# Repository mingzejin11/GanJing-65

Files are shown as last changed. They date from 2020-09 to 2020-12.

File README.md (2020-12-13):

# GanJing 65
**A 65% keyboard with a rotary encoder, OLED screen and USB-c. Made using only through-hole components for easy soldering.**

[Bill of materials](https://octopart.com/bom-tool/HPiXAxIx)

## Layout options
The GanJing 65 supports ISO layouts, as well as stepped caps lock keys. The bottom row also supports alternate layouts.

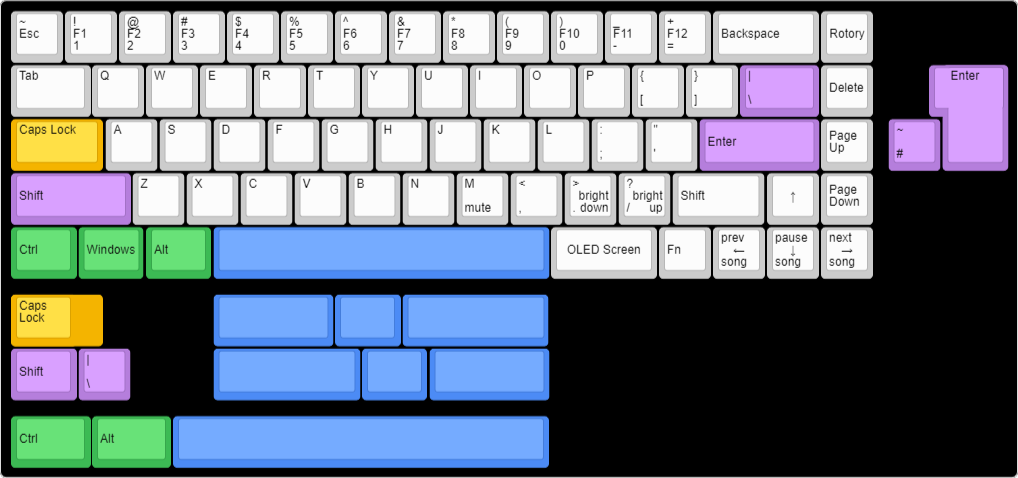
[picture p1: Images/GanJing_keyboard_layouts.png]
GanJing-keyboard

## Schematic
Inspired by the [Discipline](https://github.com/coseyfannitutti/discipline) and [Pheromone](https://github.com/luantty2/pheromone_keyboard) keyboards.

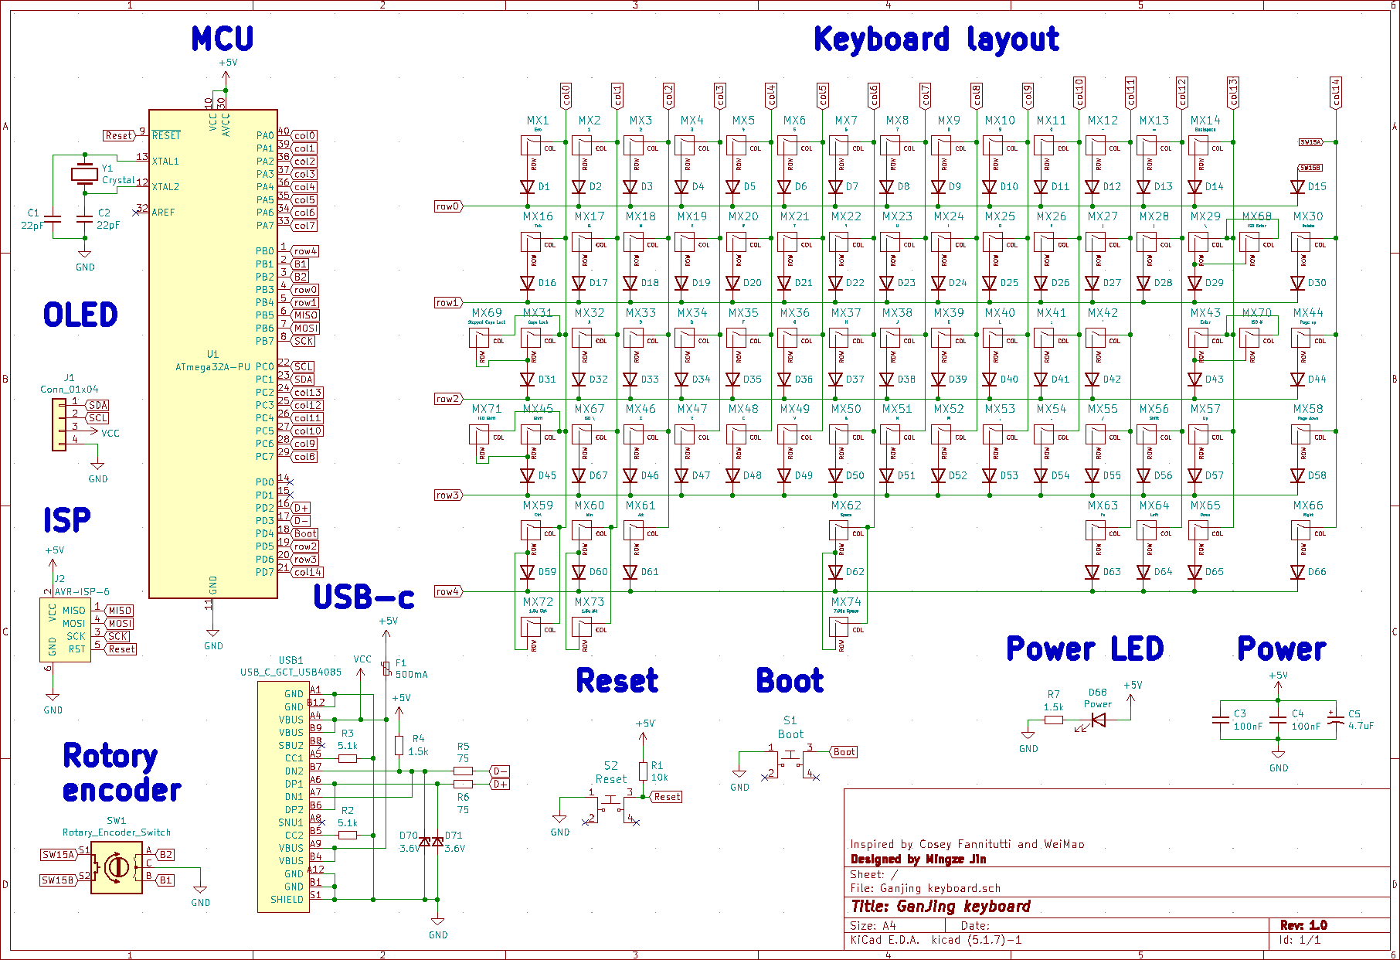
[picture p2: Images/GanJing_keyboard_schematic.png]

## PCB layout
### Front
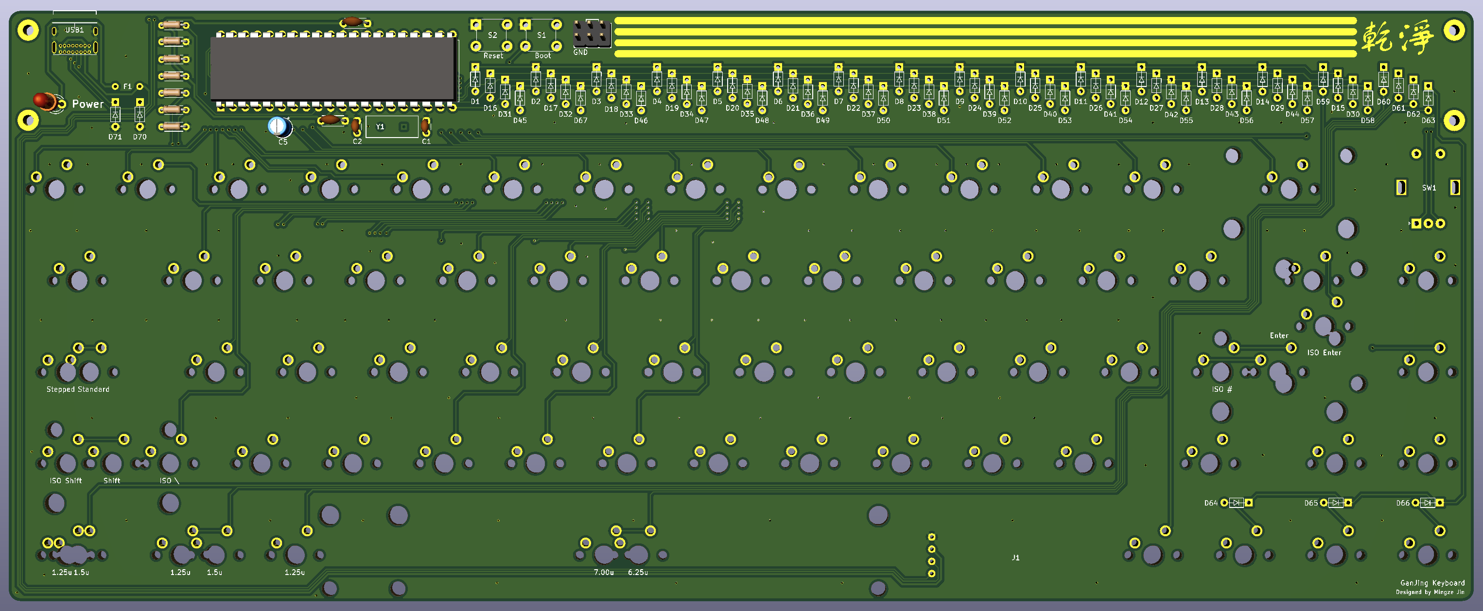
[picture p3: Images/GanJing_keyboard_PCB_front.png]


### Back
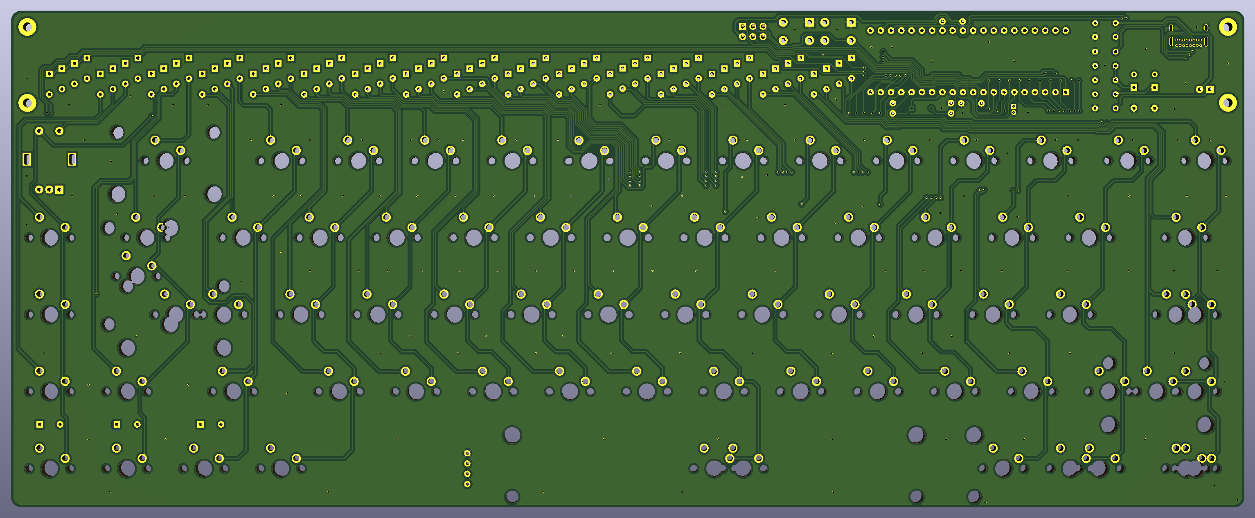
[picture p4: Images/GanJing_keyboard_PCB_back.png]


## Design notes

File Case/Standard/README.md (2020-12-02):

# Lasercut Acrylic Case

GanJing keyboard acrylic case inspired by the discipline case. The entire case is made of clear acrylic, but if you want to print your own, feel free to use different colours or even materials (recommended alternative to acrylic is POM for the plate piece).

## Part Dimensions/Thickness (Top to Bottom)
1. GanJing-top-1.dxf - 320.9 x 138.8 mm - ***3mm***
2. GanJing-top-2.dxf - 320.9 x 138.8 mm - ***4.5mm***
3. GanJing-plate.dxf - 320.9 x 138.8 mm - ***1.5mm***
4. GanJing-open-layer.dxf - 320.9 x 138.8 mm - ***4.5mm***
5. GanJing-closed-layer.dxf - 320.9 x 138.8 mm - ***3mm***
6. GanJing-bottom.dxf - 320.9 x 138.8 - ***3mm***
7. GanJing-foot-1.dxf - 276.5 x 28mm - ***4.5mm***
8. GanJing-foot-2.dxf - 272.5 x 24mm - ***4.5mm***

## Screws and Standoffs
1. 3 x m2x4 standoffs
2. 12 x m2x13 standoffs
3. 3 x m2x4mm screws
4. 24 x m2x5mm screws
5. 3 x m2x6mm screws

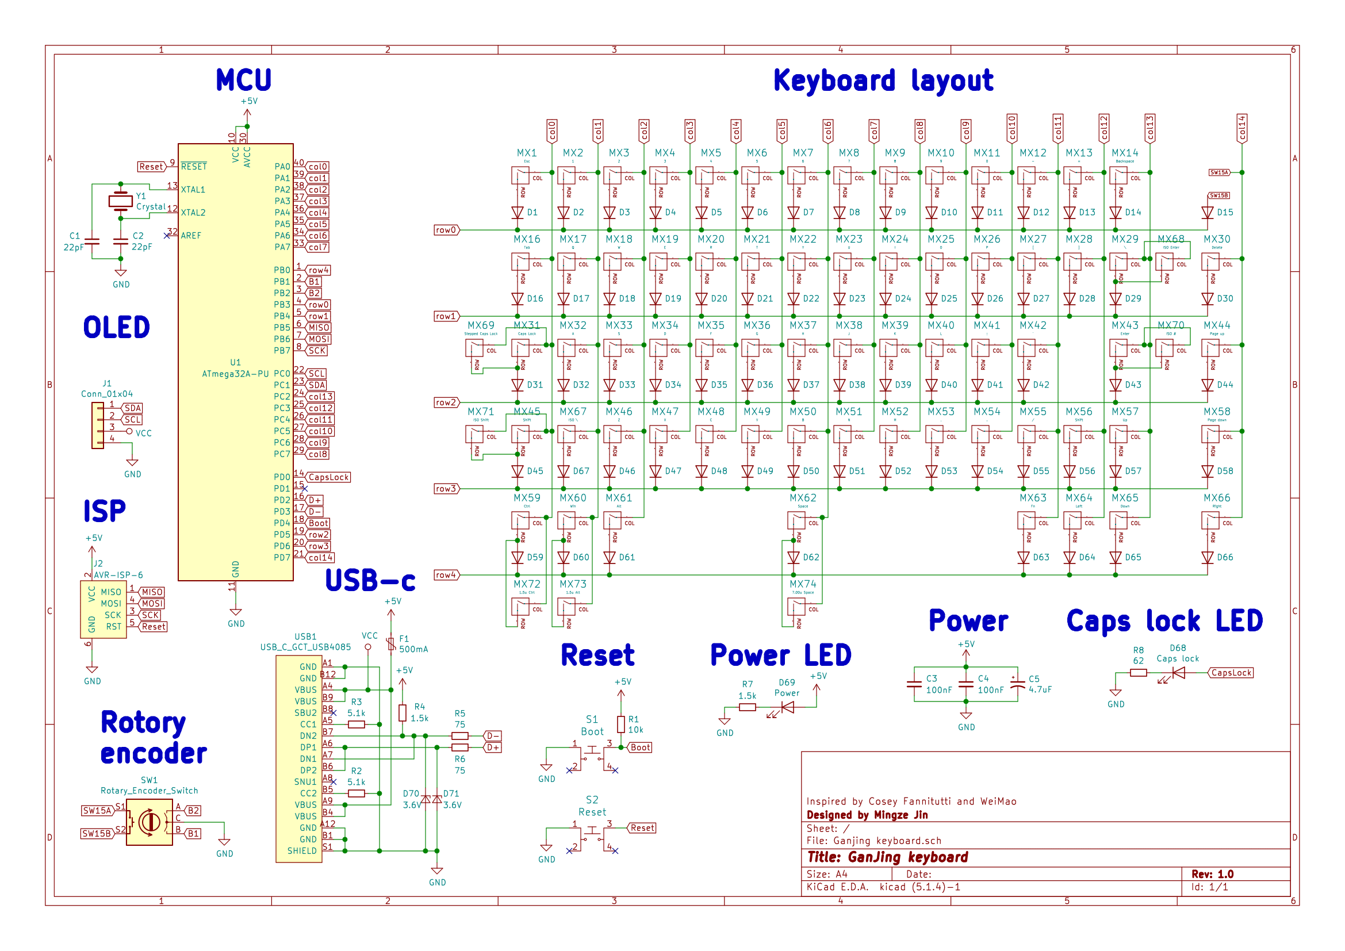
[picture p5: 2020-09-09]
Images/GanJing_keyboard_schematic 1.png

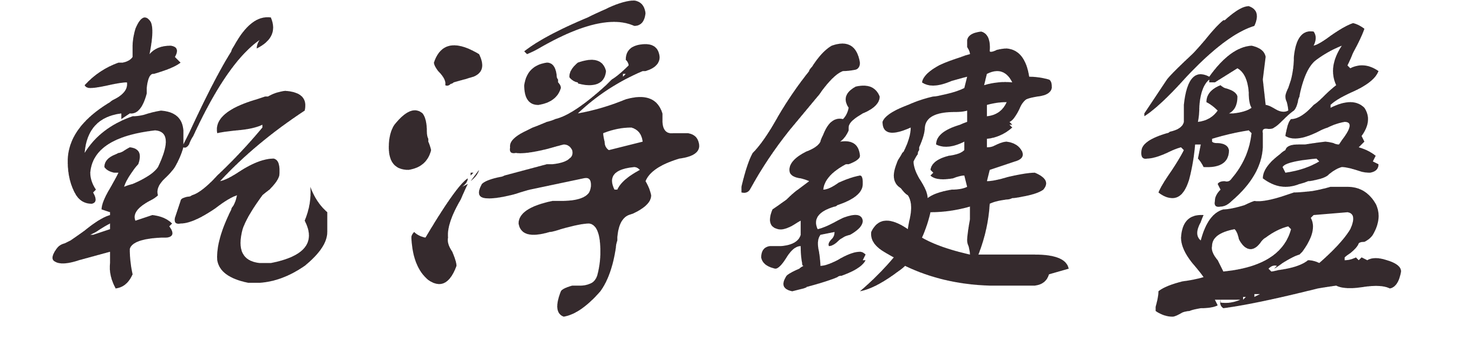
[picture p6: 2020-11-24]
Images/GanJing keyboard characters.png

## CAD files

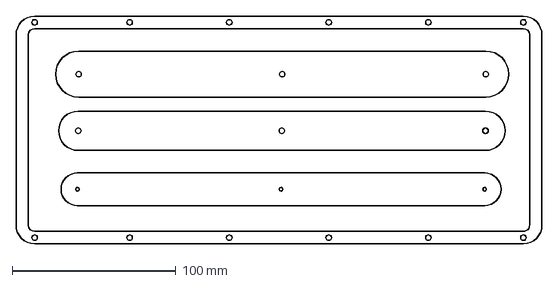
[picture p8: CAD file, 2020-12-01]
Case/Standard/GanJing-closed-layer-plus-feet.dxf
320.9 x 138.8 mm

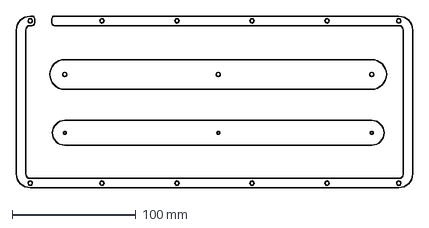
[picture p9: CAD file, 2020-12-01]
Case/Standard/GanJing-open-layer-plus-feet.dxf
320.9 x 138.8 mm

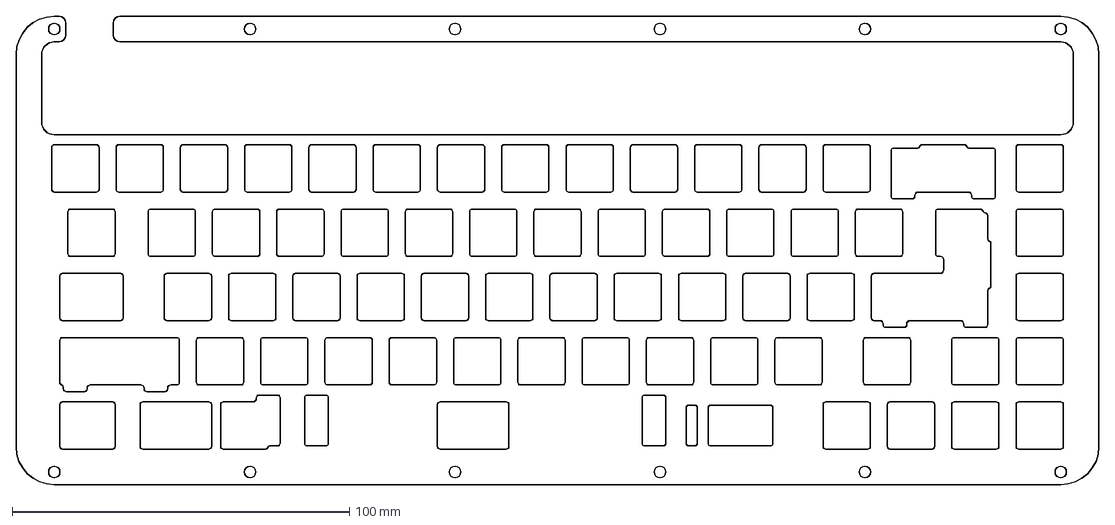
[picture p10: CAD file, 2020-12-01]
Case/Standard/GanJing-plate.dxf
320.9 x 138.8 mm

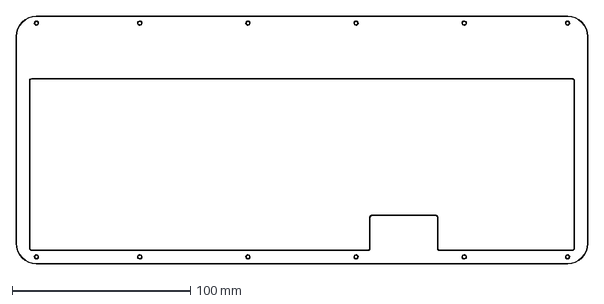
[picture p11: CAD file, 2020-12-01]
Case/Standard/GanJing-top-1.dxf
320.9 x 138.8 mm

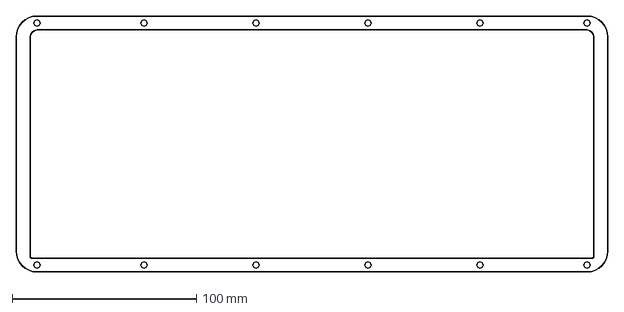
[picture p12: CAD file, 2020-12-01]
Case/Standard/GanJing-top-2.dxf
320.9 x 138.8 mm

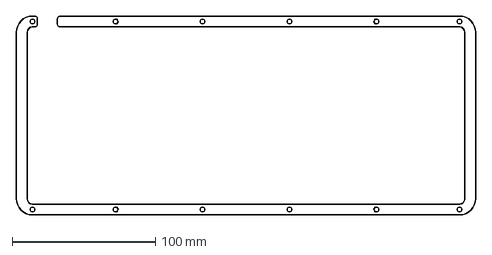
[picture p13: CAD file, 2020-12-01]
Case/Standard/GanJing-open-layer.dxf
320.9 x 138.8 mm

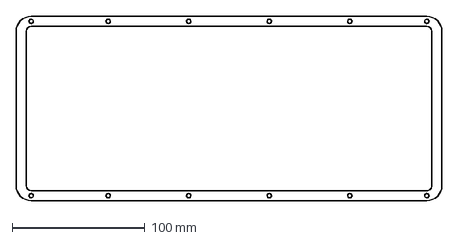
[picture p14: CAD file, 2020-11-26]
Case/Standard/GanJing-closed-layer.dxf
320.9 x 138.8 mm

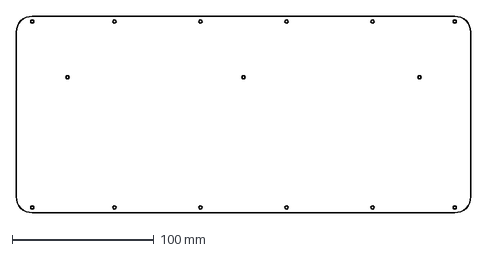
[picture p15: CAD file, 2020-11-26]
Case/Standard/GanJing-bottom.dxf
320.9 x 138.8 mm

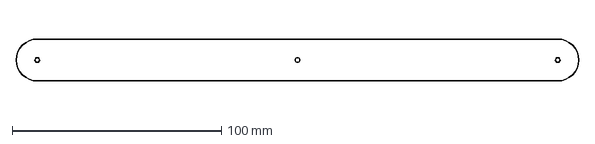
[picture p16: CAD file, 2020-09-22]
Case/Standard/GanJing-foot-2.dxf
268.5 x 20.0 mm

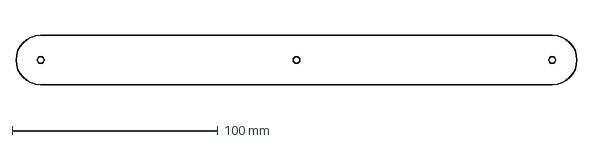
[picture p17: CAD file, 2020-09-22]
Case/Standard/GanJing-foot-1.dxf
272.5 x 24.0 mm

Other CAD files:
Case/Standard/GanJing.Drawing.JD.dwg

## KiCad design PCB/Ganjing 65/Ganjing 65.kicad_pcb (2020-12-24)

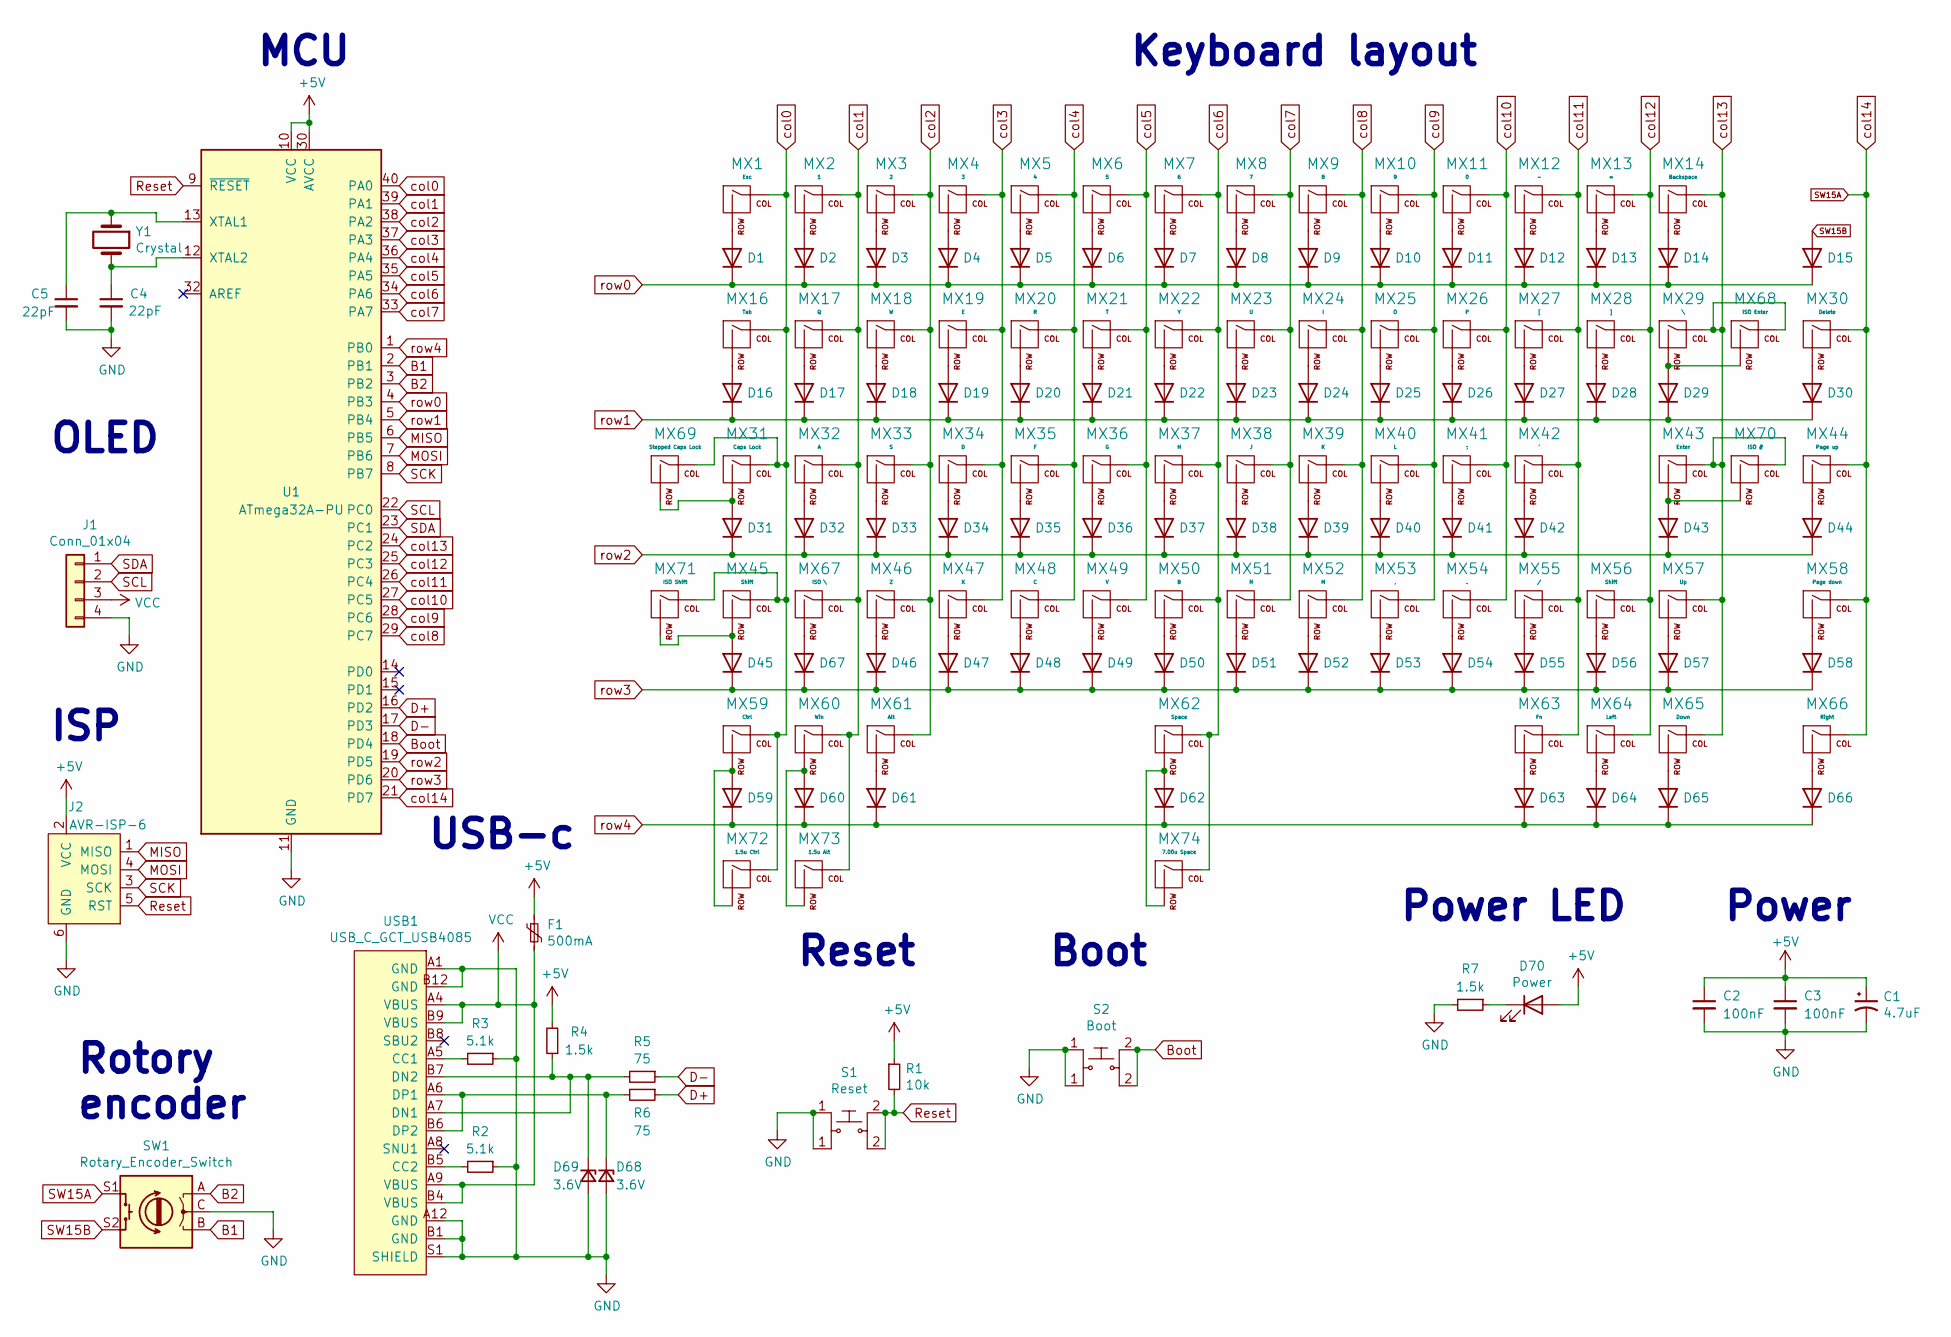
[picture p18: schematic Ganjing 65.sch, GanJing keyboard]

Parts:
C1: 4.7uF; CP_Radial_D4.0mm_P1.50mm; Mouser # 647-UMT1H4R7MDD1TP
C2, C3: 100nF; C_Disc_D4.3mm_W1.9mm_P5.00mm
C4, C5: 22pF; C_Disc_D3.0mm_W1.6mm_P2.50mm; Digikey # 490-11879-ND
D1, D2, D3, D4, D5, D6, D7, D8, D9, D10, D11, D12, D13, D14, D15, D16, D17, D18, D19, D20, D21, D22, D23, D24, D25, D26, D27, D28, D29, D30, D31, D32, D33, D34, D35, D36, D37, D38, D39, D40, D41, D42, D43, D44, D45, D46, D47, D48, D49, D50, D51, D52, D53, D54, D55, D56, D57, D58, D59, D60, D61, D62, D63, D64, D65, D66, D67: D; D_DO-35_SOD27_P5.08mm_Horizontal; Digikey # 1N4148FSTR-ND
D68, D69: 3.6V; D_DO-35_SOD27_P5.08mm_Horizontal; Mouser # 78-TZX3V6A
D70: Power; LED_D3.0mm; Digikey # 160-1140-ND
F1: 500mA; polyfuse_5.1mm; Digikey # MF-R050-ND
J1: Conn_01x04; ssd1306_128x32_oled
J2: AVR-ISP-6; AVR_ICSP_3x2; Digikey # 609-4934-ND
MX1: Esc; MXOnly-1U-NoLED
MX2: 1; MXOnly-1U-NoLED
MX3: 2; MXOnly-1U-NoLED
MX4: 3; MXOnly-1U-NoLED
MX5: 4; MXOnly-1U-NoLED
MX6: 5; MXOnly-1U-NoLED
MX7: 6; MXOnly-1U-NoLED
MX8: 7; MXOnly-1U-NoLED
MX9: 8; MXOnly-1U-NoLED
MX10: 9; MXOnly-1U-NoLED
MX11: 0; MXOnly-1U-NoLED
MX12: -; MXOnly-1U-NoLED
MX13: =; MXOnly-1U-NoLED
MX14: Backspace; MXOnly-2U-NoLED
MX16: Tab; MXOnly-1.5U-NoLED
MX17: Q; MXOnly-1U-NoLED
MX18: W; MXOnly-1U-NoLED
MX19: E; MXOnly-1U-NoLED
MX20: R; MXOnly-1U-NoLED
MX21: T; MXOnly-1U-NoLED
MX22: Y; MXOnly-1U-NoLED
MX23: U; MXOnly-1U-NoLED
MX24: I; MXOnly-1U-NoLED
MX25: O; MXOnly-1U-NoLED
MX26: P; MXOnly-1U-NoLED
MX27: [; MXOnly-1U-NoLED
MX28: ]; MXOnly-1U-NoLED
MX29: \\; MXOnly-1.5U-NoLED
MX30: Delete; MXOnly-1U-NoLED
MX31: Caps Lock; MXOnly-1.75U-NoLED
MX32: A; MXOnly-1U-NoLED
MX33: S; MXOnly-1U-NoLED
MX34: D; MXOnly-1U-NoLED
MX35: F; MXOnly-1U-NoLED
MX36: G; MXOnly-1U-NoLED
MX37: H; MXOnly-1U-NoLED
MX38: J; MXOnly-1U-NoLED
MX39: K; MXOnly-1U-NoLED
MX40: L; MXOnly-1U-NoLED
MX41: ;; MXOnly-1U-NoLED
MX42: '; MXOnly-1U-NoLED
MX43: Enter; MXOnly-2.25U-NoLED
MX44: Page up; MXOnly-1U-NoLED
MX45: Shift; MXOnly-2.25U-NoLED
MX46: Z; MXOnly-1U-NoLED
MX47: X; MXOnly-1U-NoLED
MX48: C; MXOnly-1U-NoLED
MX49: V; MXOnly-1U-NoLED
MX50: B; MXOnly-1U-NoLED
MX51: N; MXOnly-1U-NoLED
MX52: M; MXOnly-1U-NoLED
MX53: ,; MXOnly-1U-NoLED
MX54: .; MXOnly-1U-NoLED
MX55: /; MXOnly-1U-NoLED
MX56: Shift; MXOnly-1.75U-NoLED
MX57: Up; MXOnly-1U-NoLED
MX58: Page down; MXOnly-1U-NoLED
MX59: Ctrl; MXOnly-1.25U-NoLED
MX60: Win; MXOnly-1.25U-NoLED
MX61: Alt; MXOnly-1.25U-NoLED
MX62: Space; MXOnly-6.25U-ReversedStabilizers-NoLED
MX63: Fn; MXOnly-1U-NoLED
MX64: Left; MXOnly-1U-NoLED
MX65: Down; MXOnly-1U-NoLED
MX66: Right; MXOnly-1U-NoLED
MX67: ISO \\; MXOnly-1U-NoLED
MX68: ISO Enter; MXOnly-ISO-ReversedStabilizers-NoLED
MX69: Stepped Caps Lock; MXOnly-1.75U-Stepped-NoLED
MX70: ISO #; MXOnly-1U-NoLED
MX71: ISO Shift; MXOnly-1.25U-NoLED
MX72: 1.5u Ctrl; MXOnly-1.5U-NoLED
MX73: 1.5u Alt; MXOnly-1.5U-NoLED
MX74: 7.00u Space; MXOnly-7U-ReversedStabilizers-NoLED
R1: 10k; R_Axial_DIN0204_L3.6mm_D1.6mm_P5.08mm_Horizontal
R2, R3: 5.1k; R_Axial_DIN0204_L3.6mm_D1.6mm_P5.08mm_Horizontal; Mouser # 603-MFR-12FTF52-5K1
R4, R7: 1.5k; R_Axial_DIN0204_L3.6mm_D1.6mm_P5.08mm_Horizontal; Mouser # 603-MFR-12FTF52-1K5
R5, R6: 75; R_Axial_DIN0204_L3.6mm_D1.6mm_P5.08mm_Horizontal; Mouser # 603-CFR-12JR-52-75R
S1: Reset; SW_PUSH_6mm
S2: Boot; SW_PUSH_6mm
SW1: Rotary_Encoder_Switch; RotaryEncoder_Alps_EC11E-Switch_Vertical_H20mm; Mouser # 688-EC11E183440C
U1: ATmega32A-PU; DIP-40_W15.24mm; Digikey # ATMEGA32A-PU-ND
USB1: USB_C_GCT_USB4085; Digikey # 2073-USB4085-GF-ATR-ND
Y1: Crystal; Crystal_HC49-4H_Vertical; Mouser # 815-ABL16000MHZB4YT

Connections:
+5V: C1.1, C2.1, C3.1, D70.2 (A), F1.1, J2.2 (VCC), R1.1, R4.2, U1.10 (VCC), U1.30 (AVCC)
B1: SW1.B, U1.2 (PB1)
B2: SW1.A, U1.3 (PB2)
Boot: S2.2, U1.18 (PD4)
D+: R6.1, U1.16 (PD2)
D-: R5.1, U1.17 (PD3)
GND: C1.2, C2.2, C3.2, C4.2, C5.2, D68.2 (A), D69.2 (A), J1.4, J2.6 (GND), R2.1, R3.1, R7.2, S1.1, S2.1, SW1.C, U1.11 (GND), U1.31 (GND), USB1.A1 (GND), USB1.A12 (GND), USB1.B1 (GND), USB1.B12 (GND), USB1.S1 (SHIELD)
MISO: J2.1 (MISO), U1.6 (PB5)
MOSI: J2.4 (MOSI), U1.7 (PB6)
unnamed: C4.1, U1.12 (XTAL2), Y1.2
unnamed: C5.1, U1.13 (XTAL1), Y1.1
unnamed: D1.2, MX1.2 (ROW)
unnamed: D2.2, MX2.2 (ROW)
unnamed: D3.2, MX3.2 (ROW)
unnamed: D4.2, MX4.2 (ROW)
unnamed: D5.2, MX5.2 (ROW)
unnamed: D6.2, MX6.2 (ROW)
unnamed: D7.2, MX7.2 (ROW)
unnamed: D8.2, MX8.2 (ROW)
unnamed: D9.2, MX9.2 (ROW)
unnamed: D10.2, MX10.2 (ROW)
unnamed: D11.2, MX11.2 (ROW)
unnamed: D12.2, MX12.2 (ROW)
unnamed: D13.2, MX13.2 (ROW)
unnamed: D14.2, MX14.2 (ROW)
unnamed: D16.2, MX16.2 (ROW)
unnamed: D17.2, MX17.2 (ROW)
unnamed: D18.2, MX18.2 (ROW)
unnamed: D19.2, MX19.2 (ROW)
unnamed: D20.2, MX20.2 (ROW)
unnamed: D21.2, MX21.2 (ROW)
unnamed: D22.2, MX22.2 (ROW)
unnamed: D23.2, MX23.2 (ROW)
unnamed: D24.2, MX24.2 (ROW)
unnamed: D25.2, MX25.2 (ROW)
unnamed: D26.2, MX26.2 (ROW)
unnamed: D27.2, MX27.2 (ROW)
unnamed: D28.2, MX28.2 (ROW)
unnamed: D29.2, MX29.2 (ROW), MX68.2 (ROW)
unnamed: D30.2, MX30.2 (ROW)
unnamed: D31.2, MX31.2 (ROW), MX69.2 (ROW)
unnamed: D32.2, MX32.2 (ROW)
unnamed: D33.2, MX33.2 (ROW)
unnamed: D34.2, MX34.2 (ROW)
unnamed: D35.2, MX35.2 (ROW)
unnamed: D36.2, MX36.2 (ROW)
unnamed: D37.2, MX37.2 (ROW)
unnamed: D38.2, MX38.2 (ROW)
unnamed: D39.2, MX39.2 (ROW)
unnamed: D40.2, MX40.2 (ROW)
unnamed: D41.2, MX41.2 (ROW)
unnamed: D42.2, MX42.2 (ROW)
unnamed: D43.2, MX43.2 (ROW), MX70.2 (ROW)
unnamed: D44.2, MX44.2 (ROW)
unnamed: D45.2, MX45.2 (ROW), MX71.2 (ROW)
unnamed: D46.2, MX46.2 (ROW)
unnamed: D47.2, MX47.2 (ROW)
unnamed: D48.2, MX48.2 (ROW)
unnamed: D49.2, MX49.2 (ROW)
unnamed: D50.2, MX50.2 (ROW)
unnamed: D51.2, MX51.2 (ROW)
unnamed: D52.2, MX52.2 (ROW)
unnamed: D53.2, MX53.2 (ROW)
unnamed: D54.2, MX54.2 (ROW)
unnamed: D55.2, MX55.2 (ROW)
unnamed: D56.2, MX56.2 (ROW)
unnamed: D57.2, MX57.2 (ROW)
unnamed: D58.2, MX58.2 (ROW)
unnamed: D59.2, MX59.2 (ROW), MX72.2 (ROW)
unnamed: D60.2, MX60.2 (ROW), MX73.2 (ROW)
unnamed: D61.2, MX61.2 (ROW)
unnamed: D62.2, MX62.2 (ROW), MX74.2 (ROW)
unnamed: D63.2, MX63.2 (ROW)
unnamed: D64.2, MX64.2 (ROW)
unnamed: D65.2, MX65.2 (ROW)
unnamed: D66.2, MX66.2 (ROW)
unnamed: D67.2, MX67.2 (ROW)
unnamed: D68.1 (K), R6.2, USB1.A6 (DP1), USB1.B6 (DP2)
unnamed: D69.1 (K), R4.1, R5.2, USB1.A7 (DN1), USB1.B7 (DN2)
unnamed: D70.1 (K), R7.1
unnamed: R2.2, USB1.B5 (CC2)
unnamed: R3.2, USB1.A5 (CC1)
Reset: J2.5 (RST), R1.2, S1.2, U1.9 (~RESET)
SCK: J2.3 (SCK), U1.8 (PB7)
SCL: J1.2, U1.22 (PC0)
SDA: J1.1, U1.23 (PC1)
SW15A: MX30.1 (COL), MX44.1 (COL), MX58.1 (COL), MX66.1 (COL), SW1.S1, U1.21 (PD7)
SW15B: D15.2, SW1.S2
VCC: F1.2, J1.3, USB1.A4 (VBUS), USB1.A9 (VBUS), USB1.B4 (VBUS), USB1.B9 (VBUS)
col0: MX1.1 (COL), MX16.1 (COL), MX31.1 (COL), MX45.1 (COL), MX59.1 (COL), MX69.1 (COL), MX71.1 (COL), MX72.1 (COL), U1.40 (PA0)
col1: MX2.1 (COL), MX17.1 (COL), MX32.1 (COL), MX60.1 (COL), MX67.1 (COL), MX73.1 (COL), U1.39 (PA1)
col2: MX3.1 (COL), MX18.1 (COL), MX33.1 (COL), MX46.1 (COL), MX61.1 (COL), U1.38 (PA2)
col3: MX4.1 (COL), MX19.1 (COL), MX34.1 (COL), MX47.1 (COL), U1.37 (PA3)
col4: MX5.1 (COL), MX20.1 (COL), MX35.1 (COL), MX48.1 (COL), U1.36 (PA4)
col5: MX6.1 (COL), MX21.1 (COL), MX36.1 (COL), MX49.1 (COL), U1.35 (PA5)
col6: MX7.1 (COL), MX22.1 (COL), MX37.1 (COL), MX50.1 (COL), MX62.1 (COL), MX74.1 (COL), U1.34 (PA6)
col7: MX8.1 (COL), MX23.1 (COL), MX38.1 (COL), MX51.1 (COL), U1.33 (PA7)
col8: MX9.1 (COL), MX24.1 (COL), MX39.1 (COL), MX52.1 (COL), U1.29 (PC7)
col9: MX10.1 (COL), MX25.1 (COL), MX40.1 (COL), MX53.1 (COL), U1.28 (PC6)
col10: MX11.1 (COL), MX26.1 (COL), MX41.1 (COL), MX54.1 (COL), U1.27 (PC5)
col11: MX12.1 (COL), MX27.1 (COL), MX42.1 (COL), MX55.1 (COL), MX63.1 (COL), U1.26 (PC4)
col12: MX13.1 (COL), MX28.1 (COL), MX56.1 (COL), MX64.1 (COL), U1.25 (PC3)
col13: MX14.1 (COL), MX29.1 (COL), MX43.1 (COL), MX57.1 (COL), MX65.1 (COL), MX68.1 (COL), MX70.1 (COL), U1.24 (PC2)
row0: D1.1, D2.1, D3.1, D4.1, D5.1, D6.1, D7.1, D8.1, D9.1, D10.1, D11.1, D12.1, D13.1, D14.1, D15.1, U1.4 (PB3)
row1: D16.1, D17.1, D18.1, D19.1, D20.1, D21.1, D22.1, D23.1, D24.1, D25.1, D26.1, D27.1, D28.1, D29.1, D30.1, U1.5 (PB4)
row2: D31.1, D32.1, D33.1, D34.1, D35.1, D36.1, D37.1, D38.1, D39.1, D40.1, D41.1, D42.1, D43.1, D44.1, U1.19 (PD5)
row3: D45.1, D46.1, D47.1, D48.1, D49.1, D50.1, D51.1, D52.1, D53.1, D54.1, D55.1, D56.1, D57.1, D58.1, D67.1, U1.20 (PD6)
row4: D59.1, D60.1, D61.1, D62.1, D63.1, D64.1, D65.1, D66.1, U1.1 (PB0)

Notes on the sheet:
Rotory encoder
Keyboard layout
OLED
ISP
MCU
Power
Reset
Power LED
USB-c
Boot

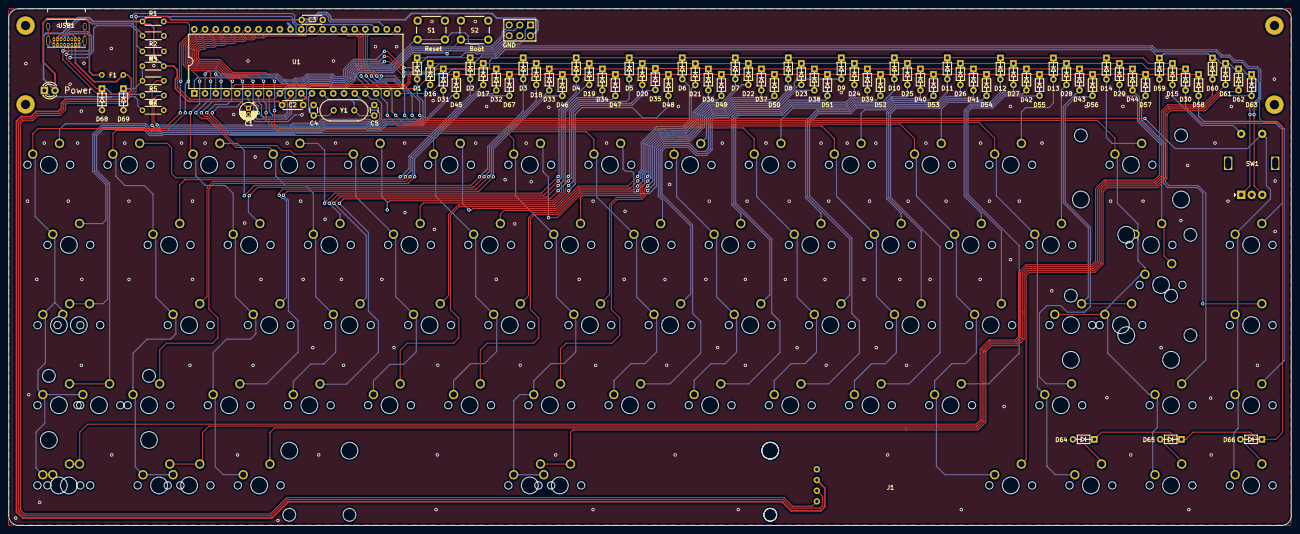
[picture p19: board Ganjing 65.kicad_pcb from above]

Board: 2 copper layers, 304.8 x 122.8 mm, 169 parts (0 on the bottom side), 108 nets.

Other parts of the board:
L1: LOGO; GanJing logo
REF1, REF2, REF6: MountingHole_2.2mm_M2_Pad
REFl: MountingHole_2.2mm_M2_Pad

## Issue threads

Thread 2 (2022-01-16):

Troubleshooting

dayofdoom, 2022-01-16:
Hello,

I've been trying to get my GanJing65 to work. I've checked all the component placements and solder joints, they appear to be without issue. The power LED lights up when plugged in. I can't get the board to be visable however - see the output from QMK toolbox.
```
    avrdude: warning: cannot set sck period. please check for usbasp firmware update.
    avrdude: error: program enable: target doesn't answer. 1
    avrdude: initialization failed, rc=-1
             Double check connections and try again, or use -F to override
             this check.

    avrdude done.  Thank you.
```

Part of my troubleshooting has been using my [LCK75](https://github.com/lyso1/LCK75) to flash the MCU since I wasn't able to with the GanJing65. I was able to successfully burn the bootloader and flash the GanJing firmware, so I know the chip is good. The computer recognized the board after flashing too.

After flashing the chip, I put it back into the GanJing but it still won't show up. It feels like there is a short somewhere or something but I've hit my skill wall and I'm not sure where to go from here. Do you have any suggestions?

mingzejin11, 2022-01-16:
First of all, lemme just start by saying I really appreciate your interest in my project! You're the first person I'm aware of who's trying to actually build it besides myself.

Onto your question, I'll be completely transparent, I ran into the same wall that you're running into right now with programming. That's why I don't have a prototype on video, I wasn't able to flash my microcontroller for the same reasons. I'm currently working on a second revision of the GanJing 65 (although I might rename it to the GanJing 70 because of the different layout), you can find it on my GitHub and it uses far fewer components and relies on the Elite-c for the MCU. I'm currently working on it right now and have a working prototype, but I'm still in 3rd-year electrical engineering so I haven't found the time to prototype the case quite yet, after this week's assignments and labs are done, I'll be laser cutting the case.

The GanJing 70 is designed to actually be gasket mounted and has a larger OLED with a Pikachu animation on it that I made(I figured the Bongo Cat one was a little overused).

Okay, I'm realizing now that I actually didn't help you at ALL with this response haha. Try checking out the bootloader stuff for the Discipline board, these two boards should use the same bootloader. That's the only real suggestion I have. I'm so sorry I can't be more help, but I promise the GanJing 70 is much easier to assemble and work with if you're up for that challenge :)

dayofdoom, 2022-01-24:
I'm going to try the make the ganjing v2, thats for sure. Looks very cool. I'm commited to getting this v1 to work too. I got the bootloader on the MCU using a different PCB (non GanJing), so I know the bootloader works ok. What I've noticed is that no matter what, when the MCU is in the GanJing, it can't be seen by the computer. The reset and boot buttons don't work either. In theroy, boot should reboot the board but the LED doesn't cycle when I press boot. My gut tells me something needs to jumpered from A to B to fix a missing connection but I'm a hobbyist, not a EE. Any thoughts?

dayofdoom, 2022-01-26:
I think the OLED pinout is reversed? See the sample image below? I think this explains why the LED was getting power but the OLED wasn't. Could this impact anything else?
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

dayofdoom, 2022-03-06:
Following up on this - I'm still not able to get the board to flash successfully BUT I've been able to flash the MCU in a different board and then get the GanJing65 to work. So, progress :) I'm going to close this because you've already moved on to v2.

Closed 2022-03-06.

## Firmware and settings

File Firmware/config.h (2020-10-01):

/* Copyright 2019 mingzejin11
 *
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
 * You should have received a copy of the GNU General Public License
 * along with this program.  If not, see <http://www.gnu.org/licenses/>.
 */

#pragma once

#include "config_common.h"

/* USB Device descriptor parameter */
#define VENDOR_ID       0x6B62
#define PRODUCT_ID      0x6869
#define DEVICE_VER      0x0001
#define MANUFACTURER    mingzejin11
#define PRODUCT         GANJING KEYBOARD
#define DESCRIPTION     65% keyboard that can be assembled with only through hole components

/* key matrix size */
#define MATRIX_ROWS 5
#define MATRIX_COLS 15

/* key matrix pins */
#define MATRIX_ROW_PINS { B3, B4, D5, D6, B0 }
#define MATRIX_COL_PINS { A0, A1, A2, A3, A4, A5, A6, A7, C7, C6, C5, C4, C3, C2, D7 }

#define OLED_FONT_H "Keymaps/glcdfont.c"

/* COL2ROW or ROW2COL */
#define DIODE_DIRECTION COL2ROW

#define USB_MAX_POWER_CONSUMPTION 100

/* Set 0 if debouncing isn't needed */
#define DEBOUNCE 5

/* If defined, GRAVE_ESC will always act as ESC when CTRL is held.
 * This is userful for the Windows task manager shortcut (ctrl + shift + esc).
 */
#define GRAVE_ESC_CTRL_OVERRIDE

#define ENCODERS_PAD_A { B2 }
#define ENCODERS_PAD_B { B1 }
#define ENCODER_RESOLUTION 4

#define BOOTMAGIC_LITE_ROW 0
#define BOOTMAGIC_LITE_COLUMN 0

#define NO_ACTION_TAPPING
#define NO_ACTION_ONESHOT
#define DISABLE_LEADER

/* Enable right shift+2 email address marco */
#define EMAIL_ENABLE
#ifdef EMAIL_ENABLE
	#define EMAIL_ADDRESS "mingze.jin11@gmail.com"
#endif

/* Enable the OLED driver */
#ifdef OLED_DRIVER_ENABLE
  	#define OLED_DISPLAY_128X32
  	#define OLED_TIMEOUT 300000	// Measured in milliseconds = 5 minutes
#endif

/*sequence for ctrl, win and alt*/
#define MOD_SEQUENCE_CWA /*normally for windows users*/
// #define MOD_SEQUENCE_CAW /*normally for macos users*/

/*other sequences*/
//#define MOD_SEQUENCE_WAC
//#define MOD_SEQUENCE_WCA
//#define MOD_SEQUENCE_AWC
//#define MOD_SEQUENCE_ACW

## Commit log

2020-08-30 inital commit
    [GanJing plate.dwg, GanJing plate.dxf, Ganjing keyboard.kicad_pcb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]
2020-09-01 Finished schematic
    [GanJing plate.dwg, Ganjing keyboard.sch]
2020-09-01 adding PDF of schematic
    [Ganjing keyboard.sch]
2020-09-01 Updated schematic with reference values
    [Ganjing keyboard.sch]
2020-09-01 Added part numbers, links, and datasheets to all symbols, as well as changing the 60 ohm resistor to 62 ohm. All symbols now have associated footprints
    [Ganjing keyboard.sch]
2020-09-01 More housekeeping
    [Ganjing keyboard.sch]
2020-09-01 Rearranging pins on MCU
    [Ganjing keyboard.sch]
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2020-09-03 Saving progress on PCB layout
    [Ganjing keyboard.kicad_pcb]
2020-09-03 Wired together all switch columns
    [Ganjing keyboard.kicad_pcb]
2020-09-03 Optimizing some routes
    [Ganjing keyboard.kicad_pcb]
2020-09-04 Finished USB-c routing
    [Ganjing keyboard.kicad_pcb, Ganjing keyboard.sch]
2020-09-04 More routing progress
    [Ganjing keyboard.kicad_pcb]
2020-09-04 More routing
    [Ganjing keyboard.kicad_pcb, Ganjing keyboard.sch]
2020-09-08 Almost done routing
    [Ganjing keyboard.kicad_pcb]
2020-09-09 routed the encoder and rearranged the diodes
    [GanJing plate.dwg, Ganjing keyboard.kicad_pcb]
2020-09-09 finished routing
    [Ganjing keyboard.kicad_pcb]
2020-09-09 adding gerber files
    [Ganjing keyboard-B_Cu.gbr, Ganjing keyboard-B_Mask.gbr, Ganjing keyboard-B_Paste.gbr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]
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2020-09-10 Cleaning up routing
    [Ganjing keyboard.kicad_pcb]
2020-09-10 More cleaning up
    [Ganjing keyboard.kicad_pcb]
2020-09-10 Even more cleaning on the bottom copper layer
    [Ganjing keyboard.kicad_pcb]
2020-09-10 Cleaning up top copper layer
    [Ganjing keyboard.kicad_pcb, Ganjing keyboard.sch]
2020-09-10 Finished cleaning up top copper pour
    [Ganjing keyboard-B_Cu.gbr, Ganjing keyboard-B_Mask.gbr, Ganjing keyboard-B_Paste.gbr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]
2020-09-10 Almost done routing clean up
    [Ganjing keyboard.kicad_pcb]
2020-09-11 Updating packages and reducing empty copper pours
    [Ganjing keyboard.kicad_pcb]
2020-09-11 Updating Gerber filesS
    [Ganjing keyboard-B_Cu.gbr, Ganjing keyboard-B_Mask.gbr, Ganjing keyboard-B_Paste.gbr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]
2020-09-11 Added remaining mounting holes
    [Ganjing keyboard-B_Cu.gbr, Ganjing keyboard-B_Mask.gbr, Ganjing keyboard-B_Paste.gbr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]
2020-09-13 Done adding via stitching
    [Ganjing keyboard.kicad_pcb]
2020-09-13 Generated Gerber files
    [Ganjing keyboard-B_Cu.gbr, Ganjing keyboard-B_Mask.gbr, Ganjing keyboard-B_Paste.gbr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]
2020-09-14 Changing footprint for crystal and adding some silk screen text
    [Ganjing keyboard-B_Cu.gbr, Ganjing keyboard-B_Mask.gbr, Ganjing keyboard-B_Paste.gbr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]
2020-09-22 Getting started on firmware and case design
    [GanJing plate.dwg, GanJing-bottom.dxf, GanJing-closed-layer.dxf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]
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2020-09-25 Fixing some silk screen stuff on the PCB
    [Ganjing keyboard.kicad_pcb]
2020-09-25 Updating Gerbers
    [Ganjing keyboard-B_Cu.gbr, Ganjing keyboard-B_Mask.gbr, Ganjing keyboard-B_Paste.gbr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]
2020-09-25 Minor mistake in text
    [Ganjing keyboard-B_Cu.gbr, Ganjing keyboard-B_Mask.gbr, Ganjing keyboard-B_Paste.gbr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]
2020-09-25 Enhancing readability of PCB
    [Ganjing keyboard-B_Cu.gbr, Ganjing keyboard-B_Mask.gbr, Ganjing keyboard-B_Paste.gbr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]
2020-09-25 Fixing some formatting
    [Ganjing keyboard-B_Cu.gbr, Ganjing keyboard-B_Mask.gbr, Ganjing keyboard-B_Paste.gbr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]
2020-09-30 Orienting USB-c cutout
    [GanJing plate.dxf, GanJing-open-layer.dxf, GanJing-plate.dxf]
2020-09-30 Upadating vias to be prettier
    [Ganjing keyboard-B_Cu.gbr, Ganjing keyboard-B_Mask.gbr, Ganjing keyboard-B_Paste.gbr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]
2020-10-01 Fixed firmware issues
    [GanJing plate.dxf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]
2020-10-01 Zip stuff
    [GanJing-bottom.dxf, GanJing-closed-layer.dxf, GanJing-open-layer.dxf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]
2020-10-27 Fixing PCB error
    [Ganjing keyboard-B_Cu.gbr, Ganjing keyboard-B_Mask.gbr, Ganjing keyboard-B_Paste.gbr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]
2020-11-21 Removing caps lock LED
    [Ganjing keyboard-B_Cu.gbr, Ganjing keyboard-B_Mask.gbr, Ganjing keyboard-B_Paste.gbr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]
2020-11-21 Updating images and generating new gerbers
    [Ganjing keyboard-B_Cu.gbr, Ganjing keyboard-B_Mask.gbr, Ganjing keyboard-B_Paste.gbr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]
2020-11-24 Adding a dope logo
    [Ganjing keyboard-B_Cu.gbr, Ganjing keyboard-B_Mask.gbr, Ganjing keyboard-B_Paste.gbr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]
2020-11-24 Removing unnecessary drill holes
    [Ganjing keyboard-B_Cu.gbr, Ganjing keyboard-B_Mask.gbr, Ganjing keyboard-B_Paste.gbr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]
2020-11-24 Cleaning up some routing
    [Ganjing keyboard-B_Cu.gbr, Ganjing keyboard-B_Mask.gbr, Ganjing keyboard-B_Paste.gbr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]
2020-11-26 Altering case to centre screw holes and adjust angle of stand to exactly 6 degrees
    [GanJing-bottom.dxf, GanJing-closed-layer.dxf, GanJing-open-layer.dxf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]
2020-11-26 Adding OLED cover and adjusting USB-c cut out
    [GanJing-open-layer.dxf, GanJing-plate.dxf, GanJing-top1.dxf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]
2020-11-26 Fixing scaling
    [GanJing-plate.dxf]
2020-12-01 Optimizing case for price
    [GanJing-open-layer.dxf, GanJing-plate.dxf, GanJing-top1.dxf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]
2020-12-01 Adding some new drawings to optomize for laser cutting
    [GanJing-closed-layer-plus-feet.dxf, GanJing-open-layer-plus-feet.dxf]
2020-12-02 Removing unnecessary files
    [GanJing-foot-1.dxf, GanJing-foot-2.dxf, GanJing-foot-3.dxf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]
2020-12-09 Adding 3d models
    [GanJing.Drawing.JD.dwg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]
2020-12-09 Fixing crystal footprint
    [Ganjing keyboard-B_Cu.gbr, Ganjing keyboard-B_Mask.gbr, Ganjing keyboard-B_Paste.gbr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]
2020-12-09 Cleaning up silk screen
    [Ganjing keyboard-B_Cu.gbr, Ganjing keyboard-B_Mask.gbr, Ganjing keyboard-B_Paste.gbr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]
2020-12-12 cleanimg up file tree
    [Ganjing keyboard-B_Cu.gbr, Ganjing keyboard-B_Mask.gbr, Ganjing keyboard-B_Paste.gbr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]
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

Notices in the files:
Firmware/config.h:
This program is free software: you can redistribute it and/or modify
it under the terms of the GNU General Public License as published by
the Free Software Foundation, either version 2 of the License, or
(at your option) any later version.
